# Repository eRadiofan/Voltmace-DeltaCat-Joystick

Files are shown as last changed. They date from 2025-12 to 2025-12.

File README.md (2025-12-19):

# Voltmace Delta-Cat Joystick Mouse Eliminator

This project documents the internals and functioning of this vintage Joystick for Acorn Archimedes computers.

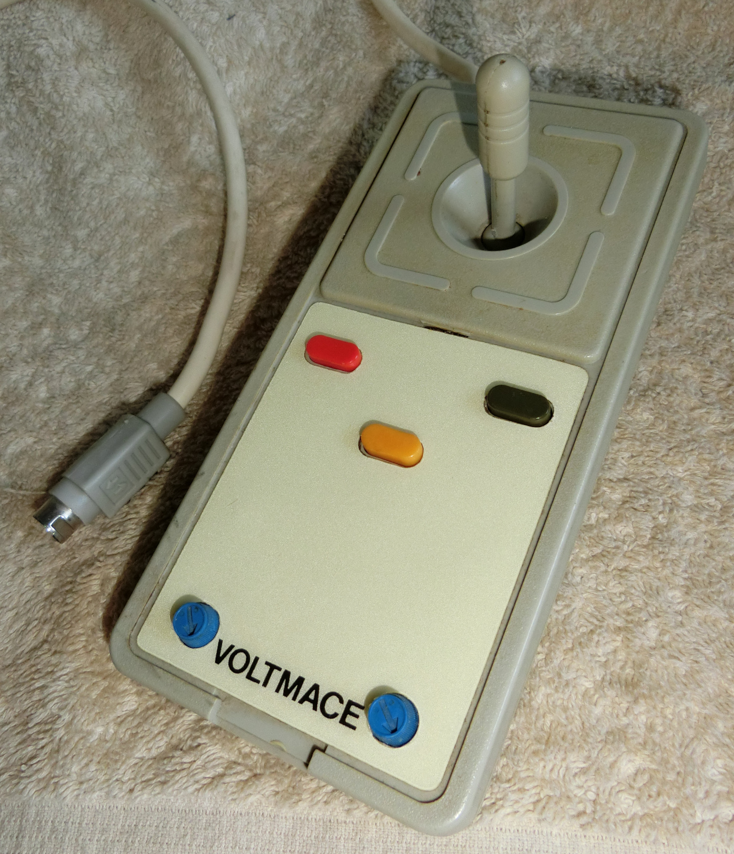
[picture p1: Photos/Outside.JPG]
Photo of Joystick


Unlike earlier BBC micros, many of the Archimedes range did not include an analog port, so Voltmace came up with this solution, which plugs into the mouse port. It was a popular option for controlling FPV games, like Zarch, Chocks Away and Elite.

The back is held on with four screws, two shorter than the others. The top and bottom of the case form a clamp around the cable, so it takes a little effort to pull the back off.

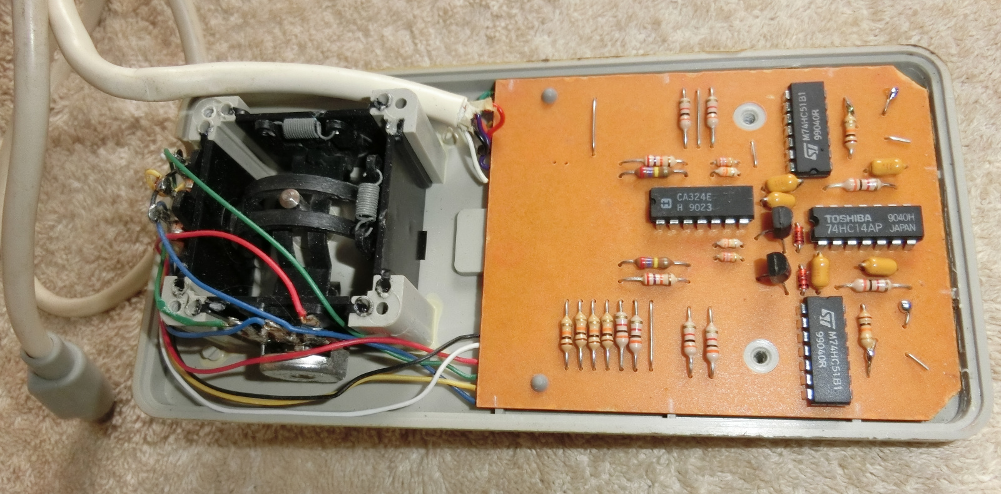
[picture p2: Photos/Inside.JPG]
Photo of top removed


Inside are the X/Y pots and a printed circuit board with (amongst other things) a quad OpAmp chip, 3 logic ICs and 2 PCB mounted pots used for controlling the vertial and horizontal speed.

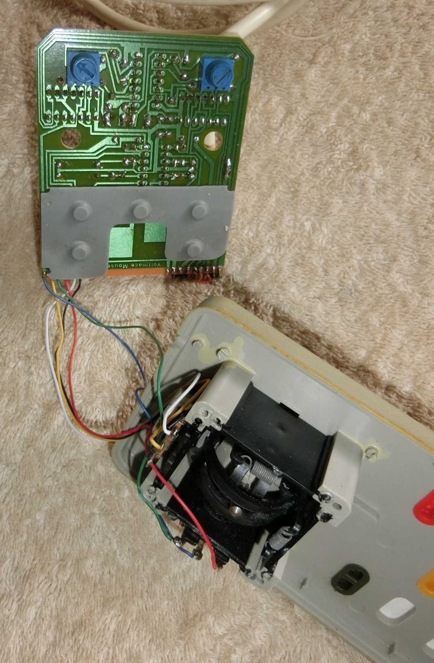
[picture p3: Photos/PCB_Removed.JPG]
Photo of underside of PCB
The buttons are rubber membrane and pop off quite easily.

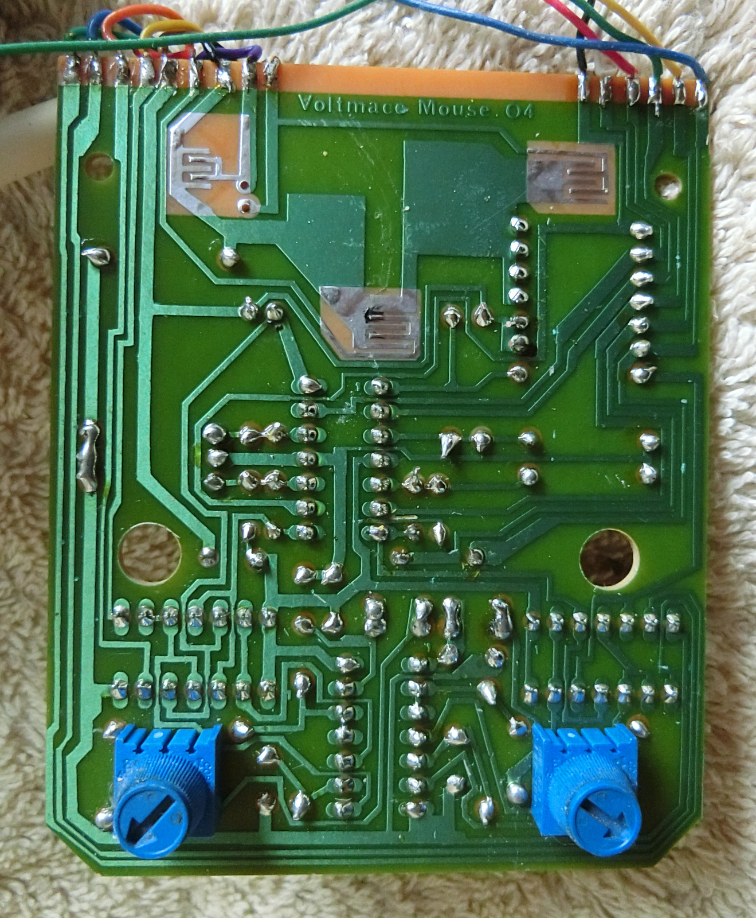
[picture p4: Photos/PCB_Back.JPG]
Photo of underside of PCB


The circuit diagram is as follows:

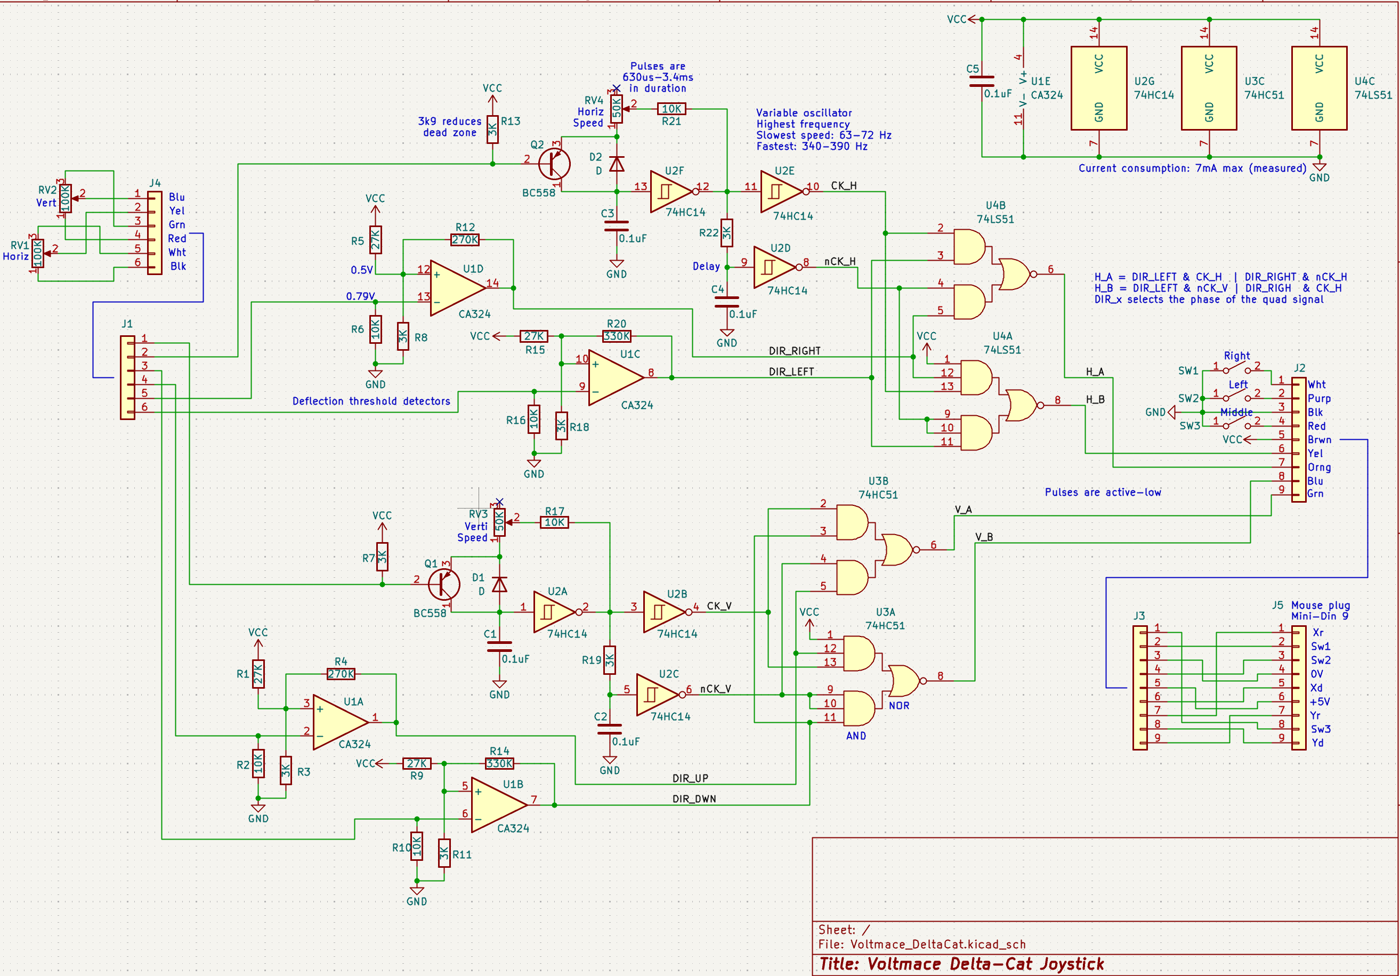
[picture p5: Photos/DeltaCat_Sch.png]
Schematic


The design is quite interesting. A positive voltage is supplied to the center of the X/Y poentiometers (via fixed resistors R7/R13) and each end of the pots are connected to ground via more resistors (R2/R6/R10/R16). The supply and ground resistors develop a small voltage across them but not enough to activate the rest of the circuit.

As the stick is moved in one direction, the drop in resistance across one side of the pot raises the voltage across some of these fixed resistors. The effects are two-fold:

1. The rise in potential across the ground resistor triggers a threshold detector (implemented by an OpAmp), indicating the direction of movement.
2. The rise in potential across the supply resistor activates a variable frequency oscillator (via transistor), that is otherwise idle. The greater the potential, the higher the frequency. The speed pots (RV3/RV4) affect the frequency range of the two oscillators.

The dead zone can be altered by adjusting R7/R13, increasing the value reduces the dead zone but beware that years of gaming introduces some play in the joystick column.

The output of the oscillator (U2A/U2F) goes into a delay gate (U2C/U2D), effectively producing the out-of-phase signal used for quadrature outputs. Both phase signals are then fed into a logic block (U3/U4) that passes them through unaltered if input is detected in one direction, or passes them reversed if input is detected in the opposite direction. The normally-high, low-going pulses are sent to the computer via the mouse port.

The PCB included in this project was intended to verify the circuit, by comparing it to the original. It is quite accurate dimensionally but the position of the speed pots might be off slightly and there are no pads for the rubber membrane keys (I have placed momenary switches instead). If you want to manufacture a PCB from this design, it will probably require a bit of tweaking. Using a modern microcontroller will probably be cheaper and the frequencies documented in the schematic should help.

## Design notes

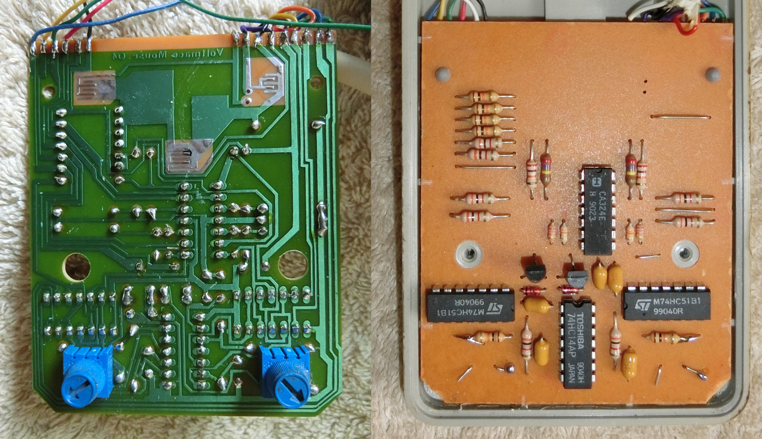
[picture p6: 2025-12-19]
Photos/PCB_FB.JPG

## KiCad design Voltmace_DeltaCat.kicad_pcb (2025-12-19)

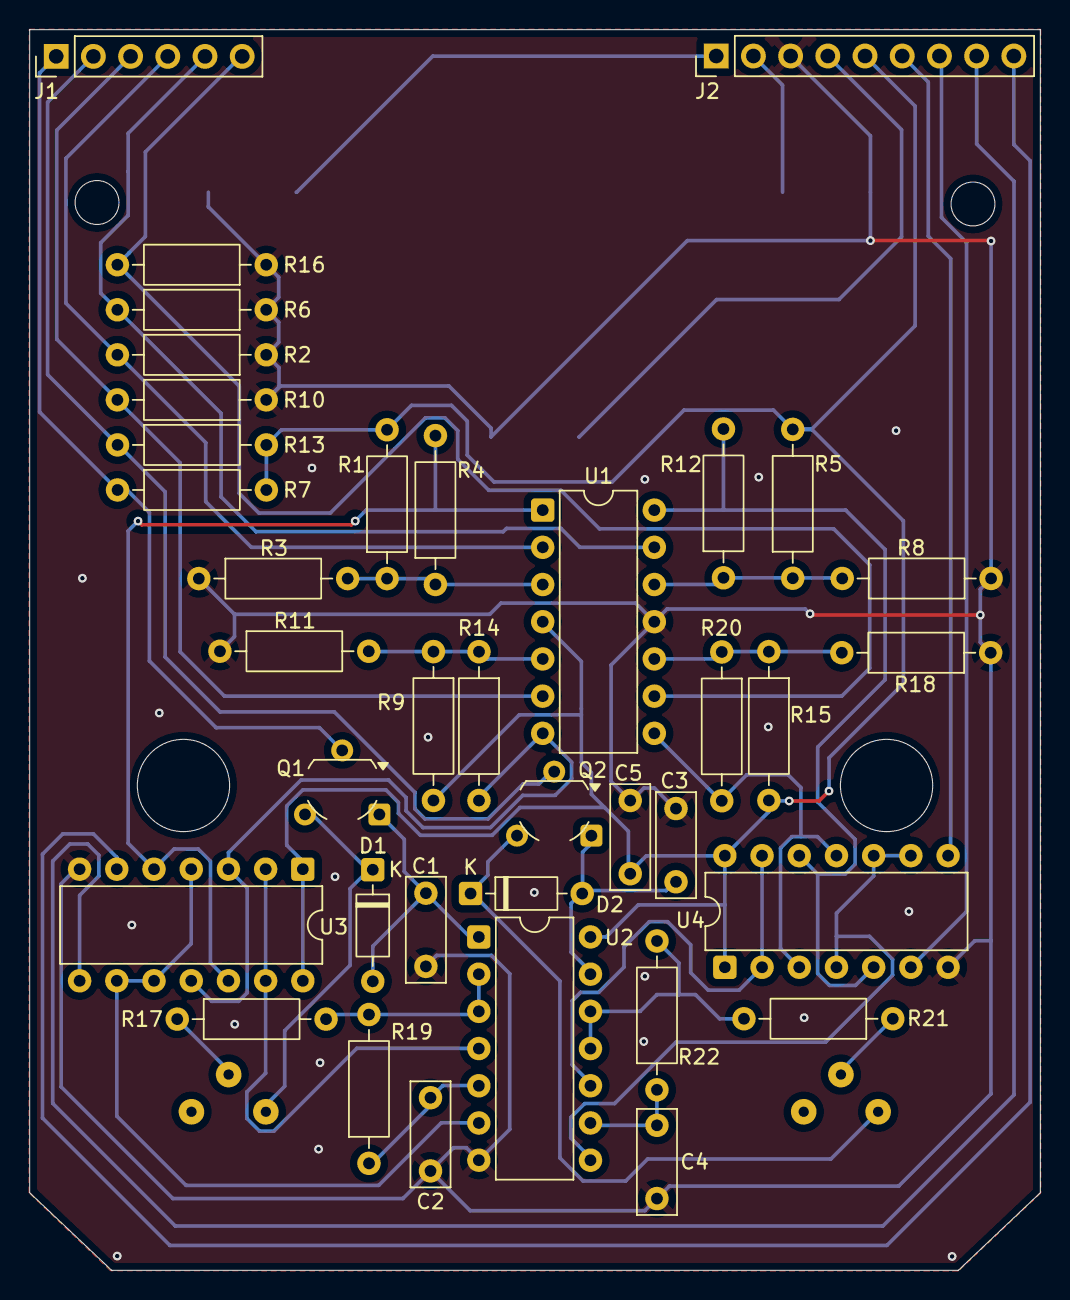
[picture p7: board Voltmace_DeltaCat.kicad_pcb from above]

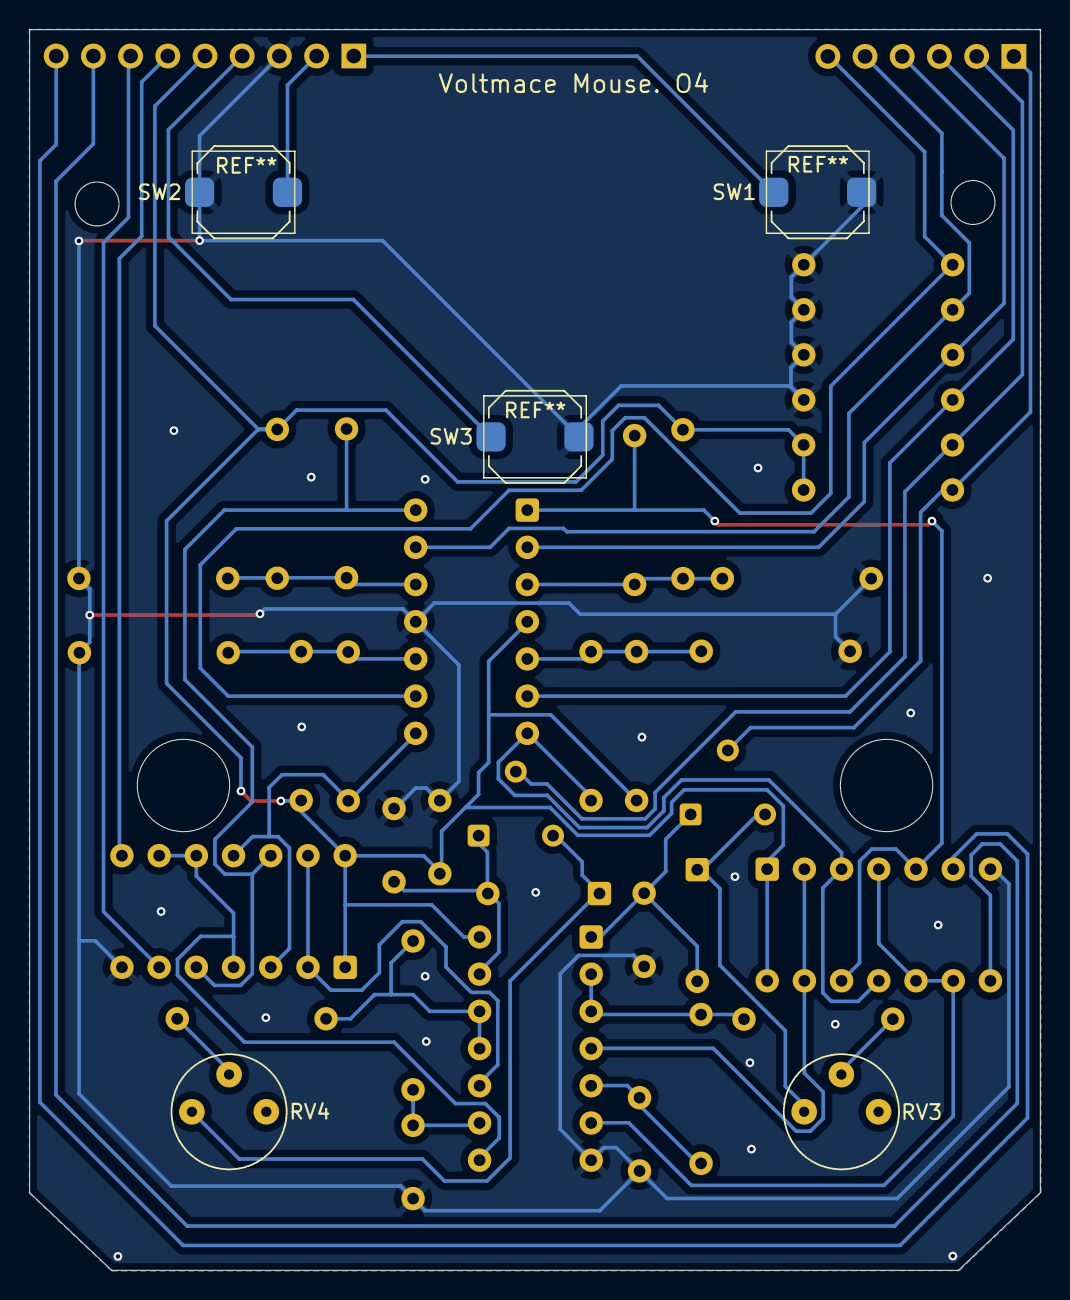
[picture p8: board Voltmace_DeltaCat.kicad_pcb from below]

Board: 2 copper layers, 69.0 x 84.7 mm, 42 parts (5 on the bottom side), 37 nets.

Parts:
C1, C2, C3, C4, C5: 0.1uF; C_Rect_L7.0mm_W2.5mm_P5.00mm
D1, D2: D; D_DO-35_SOD27_P7.62mm_Horizontal
J1: Conn_01x06; PinHeader_1x06_P2.54mm_Vertical
J2: Conn_01x09; PinHeader_1x09_P2.54mm_Vertical
Q1, Q2: BC558; TO-92_Custom
R1, R5, R9, R15: 27K; R_Axial_DIN0207_L6.3mm_D2.5mm_P10.16mm_Horizontal
R2, R6, R10, R16, R17, R21: 10K; R_Axial_DIN0207_L6.3mm_D2.5mm_P10.16mm_Horizontal
R3, R7, R8, R11, R13, R18, R19, R22: 3K; R_Axial_DIN0207_L6.3mm_D2.5mm_P10.16mm_Horizontal
R4, R12: 270K; R_Axial_DIN0207_L6.3mm_D2.5mm_P10.16mm_Horizontal
R14, R20: 330K; R_Axial_DIN0207_L6.3mm_D2.5mm_P10.16mm_Horizontal
RV3, RV4: 50K; Potentiometer_Bourns_3339P_Vertical_HandSoldering
SW1, SW2, SW3: SW_SPST; SW_Push_1TS009xxxx-xxxx-xxxx_6x6x5mm
U1: CA324; DIP-14_W7.62mm
U2: 74HC14; DIP-14_W7.62mm
U3: 74HC51; DIP-14_W7.62mm
U4: 74LS51; DIP-14_W7.62mm

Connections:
/CK_H: U2.10, U4.2, U4.13
/CK_V: U2.4, U3.2, U3.13
/DIR_DWN: R14.2, U1.7, U3.3, U3.11
/DIR_LEFT: R20.2, U1.8, U4.3, U4.11
/DIR_RIGHT: R12.2, U1.14, U4.5, U4.12
/DIR_UP: R4.2, U1.1, U3.5, U3.12
/H_A: J2.7, U4.6
/H_B: J2.6, U4.8
/V_A: J2.9, U3.6
/V_B: J2.8, U3.8
/nCK_H: U2.8, U4.4, U4.9, U4.10
/nCK_V: U2.6, U3.4, U3.9, U3.10
GND: C1.2, C2.2, C3.2, C4.2, C5.2, J2.3, R2.1, R3.1, R6.1, R8.1, R10.1, R11.1, R16.1, R18.1, SW1.1 (A), SW2.1 (A), SW3.1 (A), U1.11 (V-), U2.7 (GND), U3.7 (GND), U4.7 (GND)
unnamed: C2.1, R19.1, U2.5
unnamed: C4.1, R22.1, U2.9
unnamed: C1.1, D1.2 (A), Q1.1 (C), U2.1
unnamed: D1.1 (K), Q1.3 (E), RV3.1
unnamed: C3.1, D2.2 (A), Q2.1 (C), U2.13
unnamed: D2.1 (K), Q2.3 (E), RV4.1
unnamed: J1.1, Q1.2 (B), R7.1
unnamed: J1.2, Q2.2 (B), R13.1
unnamed: J1.3, R10.2, U1.6 (-)
unnamed: J1.4, R2.2, U1.2 (-)
unnamed: J1.5, R6.2, U1.13 (-)
unnamed: J1.6, R16.2, U1.9 (-)
unnamed: J2.1, SW1.2 (B)
unnamed: J2.2, SW2.2 (B)
unnamed: J2.4, SW3.2 (B)
unnamed: R17.1, RV3.2
unnamed: R17.2, R19.2, U2.2, U2.3
unnamed: R21.1, RV4.2
unnamed: R21.2, R22.2, U2.11, U2.12
unnamed: R1.1, R3.2, R4.1, U1.3 (+)
unnamed: R9.1, R11.2, R14.1, U1.5 (+)
unnamed: R15.1, R18.2, R20.1, U1.10 (+)
unnamed: R5.1, R8.2, R12.1, U1.12 (+)
VCC: C5.1, J2.5, R1.2, R5.2, R7.2, R9.2, R13.2, R15.2, U1.4 (V+), U2.14 (VCC), U3.1, U3.14 (VCC), U4.1, U4.14 (VCC)
